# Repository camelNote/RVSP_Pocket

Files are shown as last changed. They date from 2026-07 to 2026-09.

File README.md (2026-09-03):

 # RSVP Pocket 📖
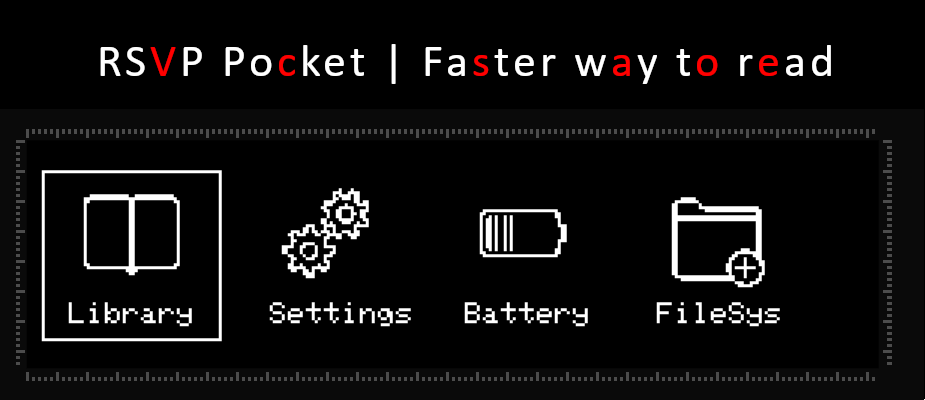
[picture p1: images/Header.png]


## Overview
### <i> How fast can you read? </i><br>
Rapid Serial Visual Presentation is a reading technique of presenting text in a single focal point to reduce eye movement. The aim is maximize reading throughput without compromising understanding.<br>

RVSP Pocket is a STM32F4 "soft" fork of the [RSVP Nano](https://github.com/ionutdecebal/rsvpnano). RVSP Pocket aims to be a more hardware optimized version of the RVSP Nano, cheaper, and more compact. Currently the project is in the protyping stage, but here's the planned features pipeline:

> Features:
> * Localized simple Angular webapp to convert .epub files into .txt file that the MCU can decode quickly
> * Single cell battery charging circuitry with overvoltage & overcurrent protection. Power mux also included to reliably switch from battery power to USB when connected, removing the possibility of calibration error in charging circuit.
> * Can act as a USB Mass Storage Class (MSC) device: Allowing user to access microSD on their laptop! Essentially can act as an USB microSD card reader (which can cost anywhere from $15 to $30!)
> * 25 MHz external HSE that enables the STM32F4 family of chips to run at maximum rated system clock of 84 Mhz.

### Current board: (It looks better in person!)
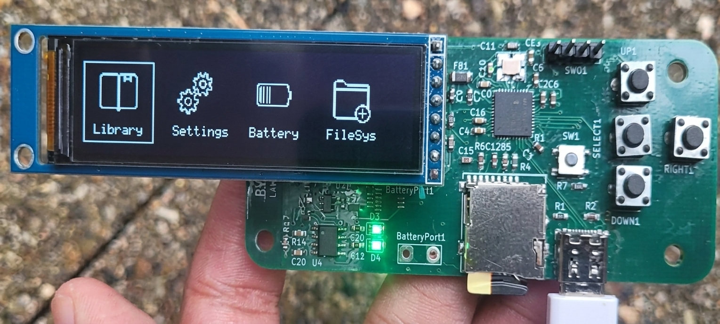
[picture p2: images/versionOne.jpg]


## Bill of materials
BOM can be found at /PCB/RSVP_Pocket.csv
* Notes: (1) the only external part not included is the TFT screen. Please use 2.25" (76x284) display module with ST7789 Driver. (2) All of these parts are interchangeable with similarly speced components. Please ensure the footprints match though!

## Installation
This project is built using platformio which is a VS Code extension. You may also choose to flash the .elf (/.pio/build/genericsSTM32F401CC/firmware.elf) using the STM32CubeProgrammer.

Using Platformio:
1. Clone the repository.
2. Open the folder in VS Code and check the platformio.ini file. Ensure that it makes the specs of your components.
3. Program via either the Serial Wire Debug header pins or USB. In your platformio.ini file, make sure to define which upload protocol is being used:
> For SWD using an STlink: upload_protocol = stlink <br>
> For USB: upload_protocol = dfu

## PCB
### 3D view
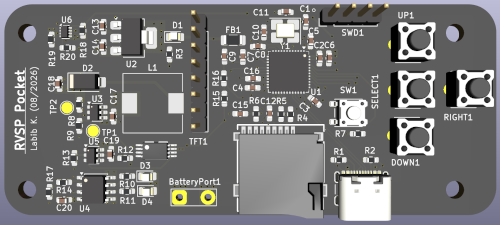
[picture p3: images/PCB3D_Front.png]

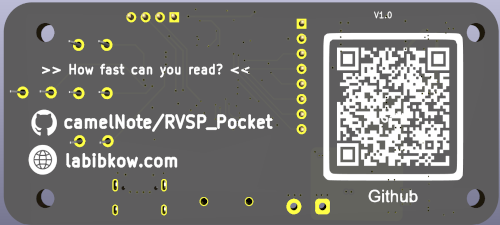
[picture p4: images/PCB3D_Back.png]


### V1 Manufractured and soldered (by hand!)
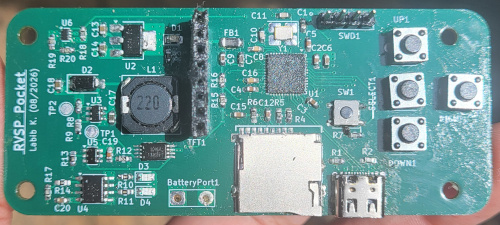
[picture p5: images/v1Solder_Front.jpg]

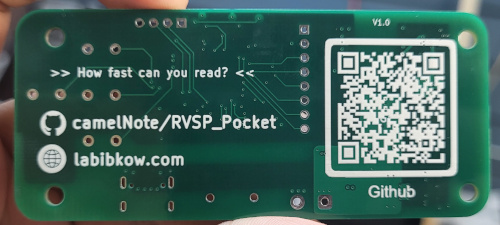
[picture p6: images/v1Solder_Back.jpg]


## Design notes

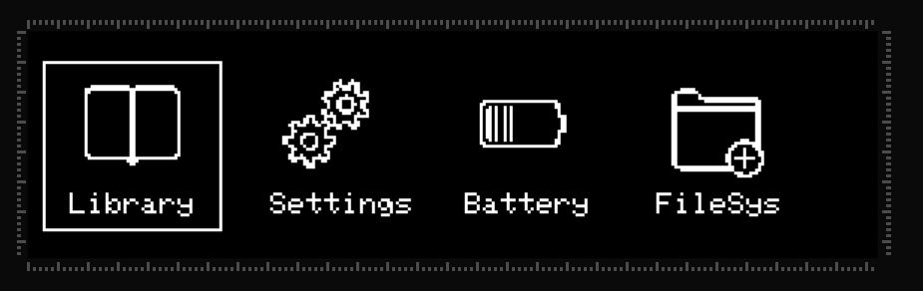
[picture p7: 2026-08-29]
images/Menu.png

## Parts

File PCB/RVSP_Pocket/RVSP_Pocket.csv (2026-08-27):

Reference | Qty | Value
BatteryPort1 | 1 | Conn_01x02
C1,C2,C3,C4,C5,C12,C19 | 7 | 100n
C6,C15,C20 | 3 | 10u
C7,C9 | 2 | 1u
C8 | 1 | 10n
C10,C11 | 2 | 10p
C13,C14 | 2 | 22u
C16 | 1 | 2.2u
C17,C18 | 2 | 22uF
D1,D4 | 2 | GREEN
D2 | 1 | SS34
D3 | 1 | BLUE
DOWN1,RIGHT1,SELECT1,UP1 | 4 | SW_Push
FB1 | 1 | 220
L1 | 1 | 22uH
MicroSD_Card1 | 1 | Micro_SD_Card
Q1 | 1 | 8205A_C5148694
R1,R2 | 2 | 5.1k
R3,R10,R11,R14 | 4 | 1k
R4,R5,R6,R18 | 4 | 10k
R7 | 1 | 43k
R8 | 1 | 390k
R9 | 1 | 51K
R12 | 1 | 470
R13 | 1 | 2k
R15,R16 | 2 | 470k
R17 | 1 | 150
R19,R20 | 2 | 47k
SW1 | 1 | SW_Push
SWD1 | 1 | Conn_01x04_Pin
TFT1 | 1 | Conn_01x08_Pin
TP1,TP2 | 2 | TestPoint
U1 | 1 | STM32F401CCUx
U2 | 1 | AMS1117-3.3
U3 | 1 | MT3608
U4 | 1 | TP4056-42-ESOP8
U5 | 1 | DW01A
U6 | 1 | TPS2116DRL
USB_C1 | 1 | USB_C_Receptacle_USB2.0_16P
Y1 | 1 | 25 Mhz

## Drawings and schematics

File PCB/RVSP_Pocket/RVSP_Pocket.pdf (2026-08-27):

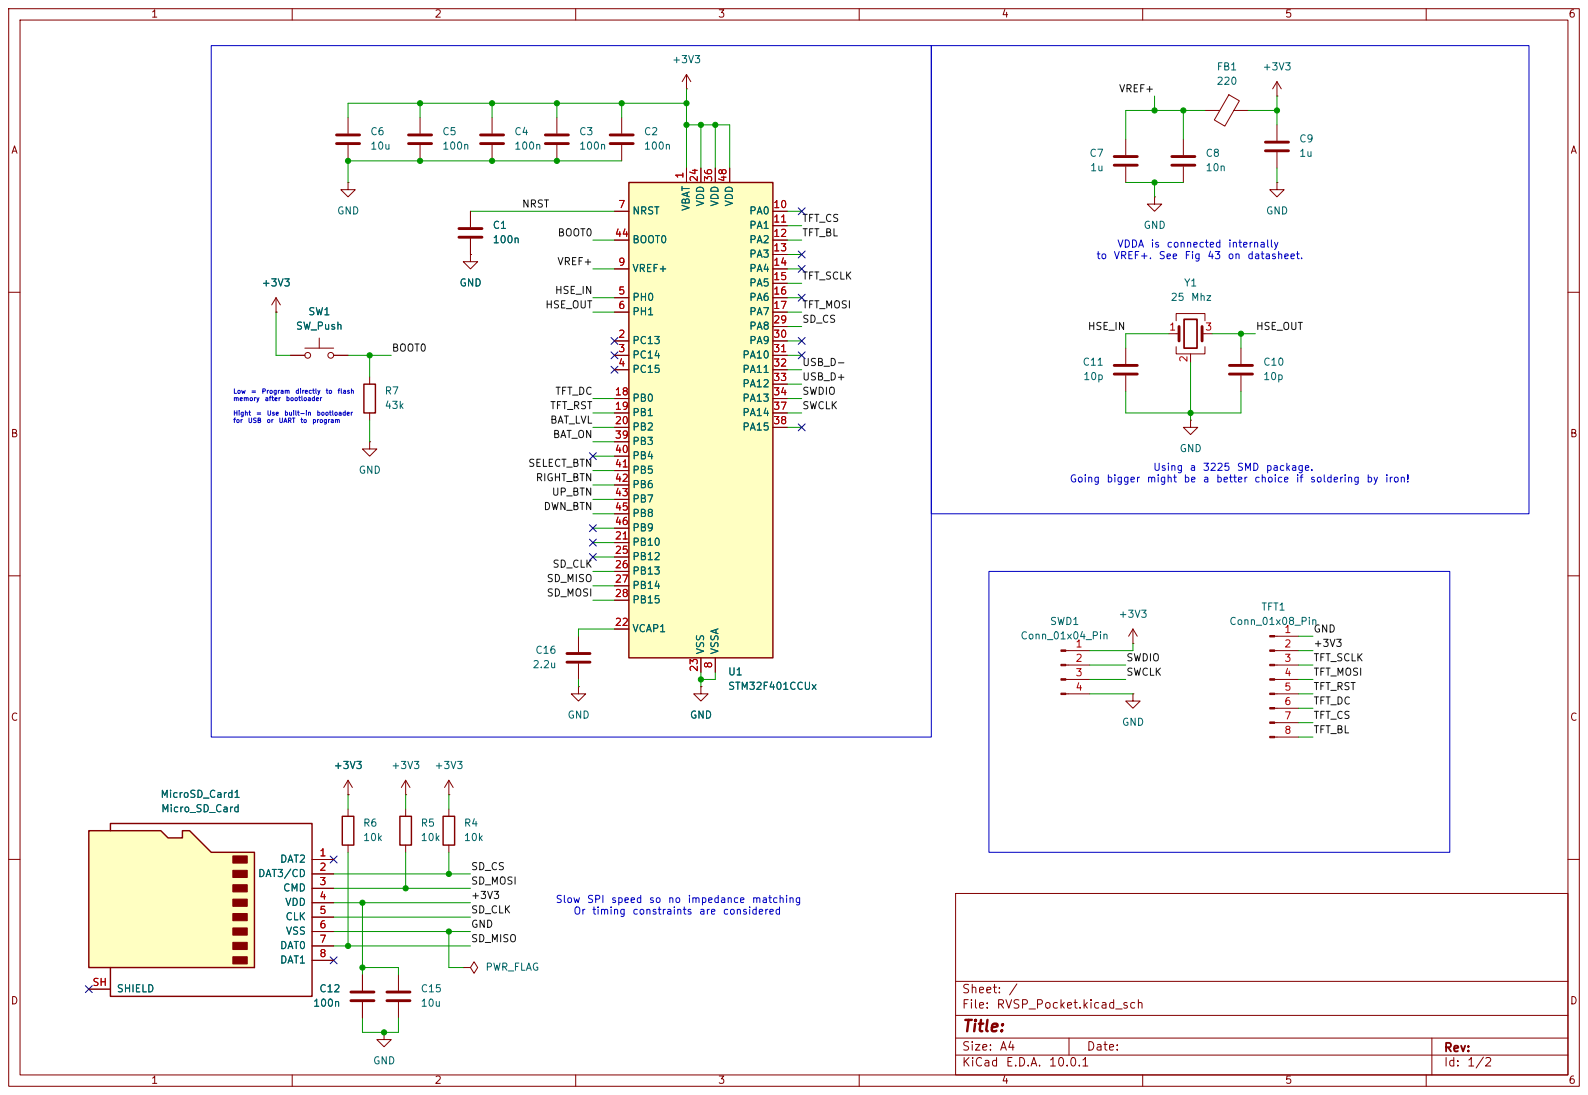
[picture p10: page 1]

GND
VDDA is connected internally

to VREF+. See Fig 43 on datasheet. Low = Program directly to flash memory after bootloader Hight = Use built-in bootloader

Size: A4 | Rev:
KiCad E.D.A. 10.0.1 | Id: 1/2

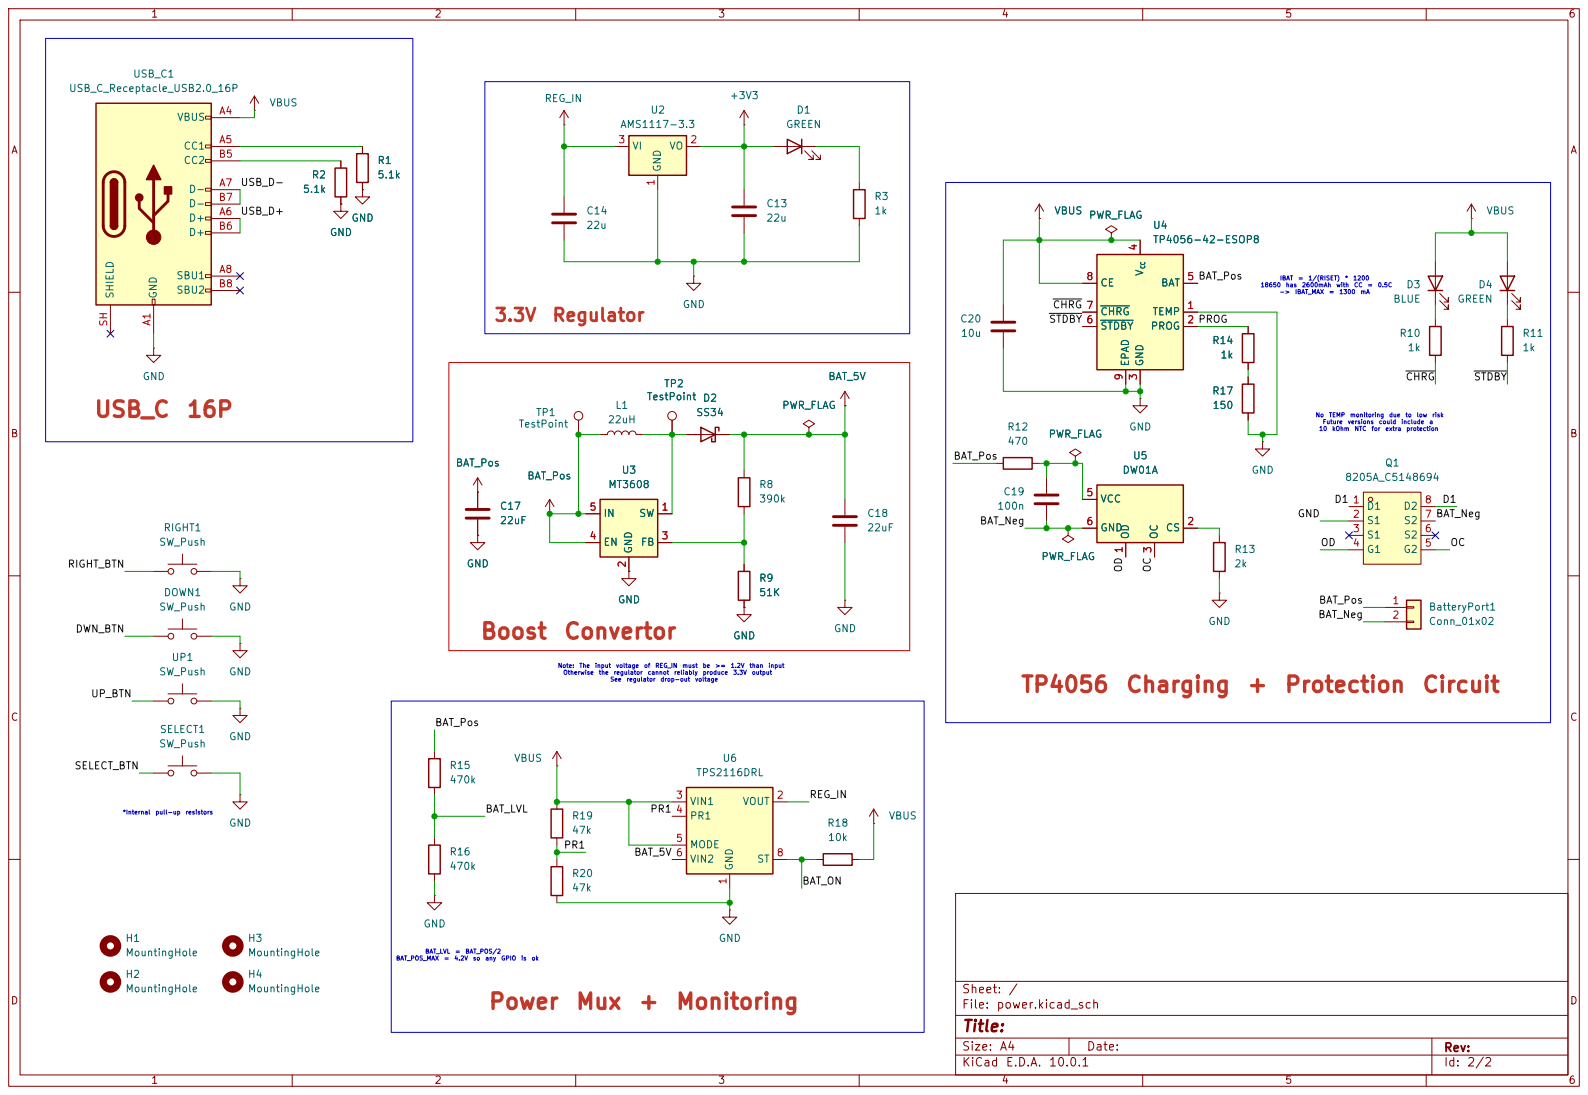
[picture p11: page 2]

18650 has 2600mAh with CC = 0.5C -> IBAT_MAX = 1300 mA Note: The input voltage of REG_IN must be >= 1.2V than input Otherwise the regulator cannot reliably produce 3.3V output See regulator drop-out voltage USB_C 16P
390k GND H2MountingHole

No TEMP monitoring due to low risk Future versions could include a 10 kOhm NTC for extra protection TP4056 Charging + Protection Circuit

Size: A4 | Rev:
KiCad E.D.A. 10.0.1 | Id: 2/2

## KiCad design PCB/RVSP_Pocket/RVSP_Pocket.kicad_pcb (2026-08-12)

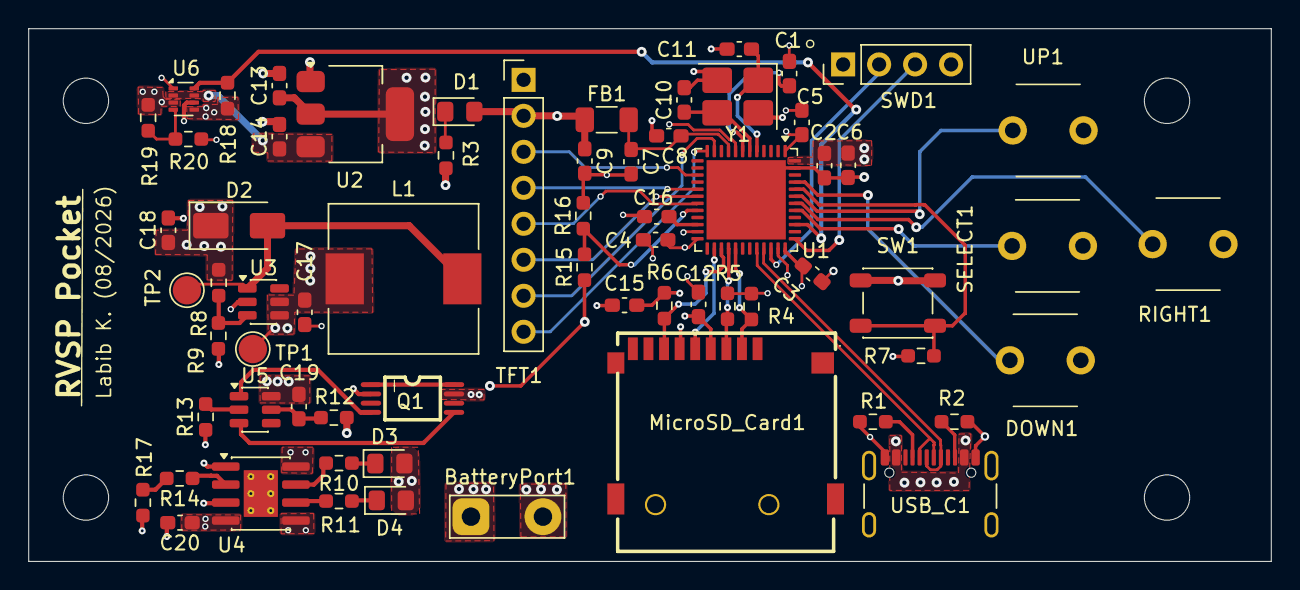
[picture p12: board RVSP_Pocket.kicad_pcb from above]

Board: 4 copper layers, 87.7 x 37.6 mm, 70 parts (0 on the bottom side), 50 nets.

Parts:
BatteryPort1: Conn_01x02; TestPoint_2Pads_Pitch5.08mm_Drill1.3mm
C1, C2, C3, C4, C5, C12, C19: 100n; C_0603_1608Metric_Pad1.08x0.95mm_HandSolder
C6, C15, C20: 10u; C_0603_1608Metric_Pad1.08x0.95mm_HandSolder
C7, C9: 1u; C_0603_1608Metric_Pad1.08x0.95mm_HandSolder
C8: 10n; C_0603_1608Metric_Pad1.08x0.95mm_HandSolder
C10, C11: 10p; C_0603_1608Metric_Pad1.08x0.95mm_HandSolder
C13, C14: 22u; C_0603_1608Metric_Pad1.08x0.95mm_HandSolder
C16: 2.2u; C_0603_1608Metric_Pad1.08x0.95mm_HandSolder
C17, C18: 22uF; C_0603_1608Metric_Pad1.08x0.95mm_HandSolder
D1, D4: GREEN; LED_0805_2012Metric_Pad1.15x1.40mm_HandSolder
D2: SS34; D_SMA
D3: BLUE; LED_0805_2012Metric_Pad1.15x1.40mm_HandSolder
DOWN1: SW_Push; SW_PUSH_6mm_H5mm_2Leg
FB1: 220; R_1206_3216Metric_Pad1.30x1.75mm_HandSolder
H1, H2, H3, H4: MountingHole; MountingHole_3.2mm_M3_DIN965
L1: 22uH; L_10.4x10.4_H4.8
MicroSD_Card1: Micro_SD_Card; TF-SMD_XKTF-N02-N
Q1: 8205A_C5148694; TSSOP-8_L4.4-W3.0-P0.65-LS6.4-BL
R1, R2: 5.1k; R_0603_1608Metric_Pad0.98x0.95mm_HandSolder
R3, R10, R11, R14: 1k; R_0603_1608Metric_Pad0.98x0.95mm_HandSolder
R4, R5, R6, R18: 10k; R_0603_1608Metric_Pad0.98x0.95mm_HandSolder
R7: 43k; R_0603_1608Metric_Pad0.98x0.95mm_HandSolder
R8: 390k; R_0603_1608Metric_Pad0.98x0.95mm_HandSolder
R9: 51K; R_0603_1608Metric_Pad0.98x0.95mm_HandSolder
R12: 470; R_0603_1608Metric_Pad0.98x0.95mm_HandSolder
R13: 2k; R_0603_1608Metric_Pad0.98x0.95mm_HandSolder
R15, R16: 470k; R_0603_1608Metric_Pad0.98x0.95mm_HandSolder
R17: 150; R_0603_1608Metric_Pad0.98x0.95mm_HandSolder
R19, R20: 47k; R_0603_1608Metric_Pad0.98x0.95mm_HandSolder
RIGHT1: SW_Push; SW_PUSH_6mm_H5mm_2Leg
SELECT1: SW_Push; SW_PUSH_6mm_H5mm_2Leg
SW1: SW_Push; SW_SPST_PTS647_Sx38
SWD1: Conn_01x04_Pin; PinHeader_1x04_P2.54mm_Vertical
TFT1: Conn_01x08_Pin; PinHeader_1x08_P2.54mm_Vertical
TP1, TP2: TestPoint; TestPoint_Pad_D2.0mm
U1: STM32F401CCUx; QFN-48-1EP_7x7mm_P0.5mm_EP5.6x5.6mm
U2: AMS1117-3.3; SOT-223-3_TabPin2
U3: MT3608; SOT-23-6
U4: TP4056-42-ESOP8; SOIC-8-1EP_3.9x4.9mm_P1.27mm_EP2.41x3.3mm_ThermalVias
U5: DW01A; SOT-23-6
U6: TPS2116DRL; SOT-583-8
UP1: SW_Push; SW_PUSH_6mm_H5mm_2Leg
USB_C1: USB_C_Receptacle_USB2.0_16P; USB_C_Receptacle_GCT_USB4105-xx-A_16P_TopMnt_Horizontal
Y1: 25 Mhz; Crystal_SMD_3225-4Pin_3.2x2.5mm_HandSoldering

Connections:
+3V3: C2.1, C3.1, C4.1, C5.1, C6.1, C9.1, C12.1, C13.1, C15.1, D1.2 (A), FB1.1, MicroSD_Card1.4 (VDD), R4.1, R5.1, R6.1, SW1.1, SWD1.1, TFT1.2, U1.1 (VBAT), U1.24 (VDD), U1.36 (VDD), U1.48 (VDD), U2.2 (VO)
/BAT_LVL: R15.2, R16.1, U1.20 (PB2)
/BAT_Neg: BatteryPort1.2, C19.2, Q1.7 (S2), U5.6 (GND)
/BAT_ON: R18.1, U1.39 (PB3), U6.8 (ST)
/BOOT0: R7.1, SW1.2, U1.44 (BOOT0)
/D1: Q1.1 (D1), Q1.8 (D2)
/DWN_BTN: DOWN1.1, U1.45 (PB8)
/HSE_IN: C11.1, U1.5 (PH0), Y1.1
/HSE_OUT: C10.1, U1.6 (PH1), Y1.3
/NRST: C1.1, U1.7 (NRST)
/OC: Q1.5 (G2), U5.3 (OC)
/OD: Q1.4 (G1), U5.1 (OD)
/PR1: R19.2, R20.1, U6.4 (PR1)
/PROG: R14.1, U4.2 (PROG)
/RIGHT_BTN: RIGHT1.1, U1.42 (PB6)
/SD_CLK: MicroSD_Card1.5 (CLK), U1.26 (PB13)
/SD_CS: MicroSD_Card1.2 (DAT3/CD), R4.2, U1.29 (PA8)
/SD_MISO: MicroSD_Card1.7 (DAT0), R6.2, U1.27 (PB14)
/SD_MOSI: MicroSD_Card1.3 (CMD), R5.2, U1.28 (PB15)
/SELECT_BTN: SELECT1.1, U1.41 (PB5)
/SWCLK: SWD1.3, U1.37 (PA14)
/SWDIO: SWD1.2, U1.34 (PA13)
/TFT_BL: TFT1.8, U1.12 (PA2)
/TFT_CS: TFT1.7, U1.11 (PA1)
/TFT_DC: TFT1.6, U1.18 (PB0)
/TFT_MOSI: TFT1.4, U1.17 (PA7)
/TFT_RST: TFT1.5, U1.19 (PB1)
/TFT_SCLK: TFT1.3, U1.15 (PA5)
/UP_BTN: U1.43 (PB7), UP1.1
/USB_D+: U1.33 (PA12), USB_C1.A6 (D+), USB_C1.B6 (D+)
/USB_D-: U1.32 (PA11), USB_C1.A7 (D-), USB_C1.B7 (D-)
/VREF+: C7.1, C8.1, FB1.2, U1.9 (VREF+)
/~CHRG: R10.2, U4.7 (~CHRG)
/~STDBY: R11.2, U4.6 (~STDBY)
BAT_5V: C18.1, D2.1 (K), R8.1, U6.6 (VIN2)
BAT_Pos: BatteryPort1.1, C17.1, L1.1, R12.1, R15.1, TP1.1 (1_1), U3.4 (EN), U3.5 (IN), U4.5 (BAT)
GND: C1.2, C2.2, C3.2, C4.2, C5.2, C6.2, C7.2, C8.2, C9.2, C10.2, C11.2, C12.2, C13.2, C14.2, C15.2, C16.2, C17.2, C18.2, C20.2, DOWN1.2, MicroSD_Card1.6 (VSS), Q1.2 (S1), R1.1, R2.1, R3.2, R7.2, R9.2, R13.1, R16.2, R17.2, R20.2, RIGHT1.2, SELECT1.2, SWD1.4, TFT1.1, U1.8 (VSSA), U1.23 (VSS), U1.35 (VSS), U1.47 (VSS), U1.49 (VSS), U2.1 (GND), U3.2 (GND), U4.1 (TEMP), U4.3 (GND), U4.9 (EPAD), U6.1 (GND), UP1.2, USB_C1.A1 (GND), USB_C1.A12 (GND), USB_C1.B1 (GND), USB_C1.B12 (GND), Y1.2 (G), Y1.4 (G)
unnamed: D1.1 (K), R3.1
unnamed: D2.2 (A), L1.2, TP2.1 (1_1), U3.1 (SW)
unnamed: D3.1 (K), R10.1
unnamed: D4.1 (K), R11.1
unnamed: R14.2, R17.1
unnamed: C16.1, U1.22 (VCAP1)
unnamed: R8.2, R9.1, U3.3 (FB)
unnamed: R13.2, U5.2 (CS)
unnamed: C19.1, R12.2, U5.5 (VCC)
unnamed: R1.2, USB_C1.A5 (CC1)
unnamed: R2.2, USB_C1.B5 (CC2)
REG_IN: C14.1, U2.3 (VI), U6.2 (VOUT), U6.7 (VOUT)
VBUS: C20.1, D3.2 (A), D4.2 (A), R18.2, R19.1, U4.4 (V_{CC}), U4.8 (CE), U6.3 (VIN1), U6.5 (MODE), USB_C1.A4 (VBUS), USB_C1.A9 (VBUS), USB_C1.B4 (VBUS), USB_C1.B9 (VBUS)

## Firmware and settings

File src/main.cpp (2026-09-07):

#include <Arduino.h>
#include <TFT_eSPI.h>

#include <NotoSansJP20.h>
#include "WordProcess.h"
#include "Menu.h"

/* Const variable definitions */
//Fonts
#define AA_FONT_SMALL NotoSansJP20
#define GFXFF 1

//Reversed due to landscape mode
#define HALF_WIDTH TFT_HEIGHT/2
#define HALF_HEIGHT TFT_WIDTH/2

#define SD_CS PA8

//Button definitions
#define RIGHT_BTN PB6
#define SELECT_BTN PB5
#define UP_BTN PB7
#define DOWN_BTN PB8

SPIClass mySPI(PB15, PB14, PB13); //MOSI, MISO, CLK, SSEL
SdSpiConfig sdSdioConfig(SD_CS, DEDICATED_SPI, SD_SCK_MHZ(40), &mySPI);

/* Global variables */
volatile bool rightBtnPressed = false;
volatile bool selectBtnPressed = false;
volatile bool upBtnPressed = false;
volatile bool downBtnPressed = false;

SdFat sd;
File32 bookFile;

TFT_eSPI tft = TFT_eSPI();

btnSelection btnStates = {0, 0, 0}; // Initialize all states to 0

char wordBuffer[WORDS_PER_CHUNK][MAX_WORD_LEN];
uint64_t endPos = 0;//Track position of cursor
int32_t readCount; //Number of words read from file

uint16_t wordSpeed = 300; //Default wpm speed;
uint16_t brightness = 100;
uint32_t delayTime = (float)60/wordSpeed * 1000; //ms delay between words

volatile unsigned long lastInterruptTime = 0;
const unsigned long debounceDelay = 20; // ms

// ISR
void rightBtnISR(){
  unsigned long currentTime = millis();
  if (currentTime - lastInterruptTime >= debounceDelay) {
    rightBtnPressed = true; 
    lastInterruptTime = currentTime;
    btnStates.menuState = (btnStates.menuState + 1) % 4; //Cycle through menu states
  }
}

void selectBtnISR(){
  unsigned long currentTime = millis();
  if (currentTime - lastInterruptTime >= debounceDelay*3) {
    selectBtnPressed = true; 
    lastInterruptTime = currentTime;
    btnStates.selectState = 1; // Toggle select state
  }
}

void upBtnISR(){
  unsigned long currentTime = millis();
  if (currentTime - lastInterruptTime >= debounceDelay) {
    upBtnPressed = true; 
    lastInterruptTime = currentTime;
    btnStates.upDownCounter += 1;
  }
}

void downBtnISR(){
  unsigned long currentTime = millis();
  if (currentTime - lastInterruptTime >= debounceDelay) {
    downBtnPressed = true; // toggle button state
    lastInterruptTime = currentTime;
    btnStates.upDownCounter = (btnStates.upDownCounter > 0)? btnStates.upDownCounter - 1: 0;
  }
}

void setup() {
  //PinMode declarations
  pinMode(RIGHT_BTN, INPUT_PULLUP);//Button
  pinMode(SELECT_BTN, INPUT_PULLUP);
  pinMode(UP_BTN, INPUT_PULLUP); 
  pinMode(DOWN_BTN, INPUT_PULLUP);
  pinMode(PC15, OUTPUT);
  pinMode(PA2, OUTPUT);

  digitalWrite(PC15, LOW);//Virtual GND
  digitalWrite(PA2, LOW);//TFT BL LOW 
  

  bool sdOK = sd.begin(sdSdioConfig);   // no "bool" — assigns the global
  //uint8_t errCode = sd.sdErrorCode();                   // no "uint8_t"
  //uint8_t errData = sd.sdErrorData();

  //Interrupts
  attachInterrupt(RIGHT_BTN, rightBtnISR, FALLING); //Active low button
  attachInterrupt(SELECT_BTN, selectBtnISR, FALLING);
  attachInterrupt(UP_BTN, upBtnISR, FALLING);
  attachInterrupt(DOWN_BTN, downBtnISR, FALLING);

  tft.init();
  tft.setRotation(3);
  tft.fillScreen(TFT_BLACK);

  if(!sdOK){
    //bookFile = sd.open("rvsp/book01.txt", FILE_READ);
    // Handle SD card initialization failure
    while(true){
      drawRVSPWord("SD_Failed", HALF_WIDTH, HALF_HEIGHT, &tft);
      delay(5000);
    } 
  }//if
}

void loop() {
  drawMenu(&tft, &btnStates, sd, bookFile, sdSdioConfig, wordSpeed, brightness);

  //Setting Constants
  delayTime = (float)60/wordSpeed * 1000;

  tft.loadFont(AA_FONT_SMALL);
  tft.setTextColor(TFT_WHITE, TFT_BLACK);
  tft.setTextDatum(MC_DATUM);
  
  drawRVSPWord("Start", HALF_WIDTH, HALF_HEIGHT, &tft);
  readCount = fetchWords(wordBuffer, &bookFile, endPos, &endPos);

  rightBtnPressed = false;
  selectBtnPressed =  false;

  tft.drawLine(143, 0, 143, 14, 0xFFFF);
  tft.drawLine(143, 61, 143, 75, 0xFFFF);
  
  while(readCount > 0){
    uint8_t counter = 0;

    while(counter < WORDS_PER_CHUNK){
      if(selectBtnPressed){
        rightBtnPressed = false;
        selectBtnPressed = false;

        //Pause
        while(!rightBtnPressed){
          if(selectBtnPressed) break;
          delay(200);
        }
        break;
      }//if
      else if(rightBtnPressed){
        drawRVSPWord(wordBuffer[counter], HALF_WIDTH, HALF_HEIGHT, &tft);
          uint8_t wordLength = strlen(wordBuffer[counter]);
          char lastChar = wordBuffer[counter][wordLength - 1];

          //Add extra delay for punctuation
          if(lastChar == '.' || lastChar == '?' || lastChar == '!' || lastChar == ',') {
            delay(delayTime * 2); 
          }else {
            delay(delayTime);
          }
          counter++;
      }//else if
    }//while

    if(selectBtnPressed && rightBtnPressed) break;

    //Fetch another batch
    readCount = fetchWords(wordBuffer, &bookFile, endPos, &endPos);

  }//while

  //End of book reached
  if(readCount == 0){
    bookFile.seek(0);
    endPos = 0;
    readCount = fetchWords(wordBuffer, &bookFile, 0, &endPos);
    drawRVSPWord("End of book", HALF_WIDTH, HALF_HEIGHT, &tft);
    delay(1000);
  }
  
  
  rightBtnPressed = false;
  selectBtnPressed =  false;
  drawRVSPWord("Returning to Menu", HALF_WIDTH, HALF_HEIGHT, &tft);
  delay(1000);
  btnStates = {0,0,0};
}

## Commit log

2026-07-28 Fixed skipping issue, invalid chars, & buffer speed
    [RVSP_Pocket.kicad_pcb, RVSP_Pocket.kicad_sch, power.kicad_sch]
2026-08-11 Added PCB files
    [RVSP_Pocket-B_Mask.gbr, RVSP_Pocket-B_Paste.gbr, RVSP_Pocket-B_Silkscreen.gbr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]
2026-08-12 Added readme
    [RVSP_Pocket-B_Mask.gbr, RVSP_Pocket-B_Paste.gbr, RVSP_Pocket-B_Silkscreen.gbr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]
2026-08-27 Working with custom PCB STM32F401CC
    [RVSP_Pocket.csv]
2026-09-04 Agent Host changes for agents/filter-txt-files-in-usb-msc
2026-09-04 Fixed Library screen to reading screen problem
    [main.cpp]
2026-09-07 Mystery chars due to uneven byte splitting in drawRVSPWord fixed
    [main.cpp]
